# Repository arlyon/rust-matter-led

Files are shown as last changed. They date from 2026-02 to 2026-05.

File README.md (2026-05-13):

# matter-led

A Matter-compatible 5-channel RGBCW LED controller built on a custom PCB
with an ESP32-C6, written entirely in Rust. Pairs natively with Apple Home,
Google Home, and any other Matter controller -- no proprietary hub required.

## Hardware

### Board

The controller is a 2-layer PCB designed in KiCad 9. It accepts 24 V DC
input through a Molex 2601-1106 connector, protected by a 10 A mini blade
fuse (Littelfuse 0297010.WXNV). A Recom R-78E5.0-1.0 switching regulator
steps 24 V down to 5 V / 1 A to power the Waveshare ESP32-C6 module. Two
470 uF electrolytic capacitors (Panasonic EEUFR1V471L) filter the converter
input.

Five AO3400A N-channel MOSFETs in SOT-23 packages switch the LED channels
on the low side. Each gate is driven from a GPIO through a 100 ohm series
resistor; 10 kohm pull-downs hold the gates low during boot. The MOSFETs
switch the 24 V rail directly, so the LED strips see full supply voltage.

### LED strip

The board drives 24 V RGBCCT LED strips with a common-anode, 6-pin
configuration (V+, R, G, B, CW, WW). The target strip uses 5050-package
RGB LEDs alongside 2835-package tunable-white LEDs, with a colour
temperature range of 2000--6500 K and a CRI of 95. At 168 LEDs/m drawing
34.56 W/m, a 5 m reel pulls around 173 W. The strip is IP20 (no
weatherproofing). Five independent PWM channels allow continuous colour
temperature tuning between 2000 K and 6500 K, as well as full-gamut RGB
colour mixing.

An example strip that matches these specs:
https://www.aliexpress.com/item/1005006132338333.html

### Power supply

Use a 24 V DC supply rated for the strip length you intend to drive. The
board fuse is 10 A, so the practical ceiling is around 240 W at the input
connector. A Mean Well LRS-350-24 or equivalent is a reasonable choice for
a full 5 m strip.

### GPIO mapping

| GPIO | Channel |
|---|---|
| 1 | Red |
| 0 | Green |
| 10 | Blue |
| 3 | Cold White |
| 2 | Warm White |
| 9 | BOOT (factory reset) |

## Firmware

The firmware is a `no_std` Rust binary targeting `riscv32imac-unknown-none-elf`.
It requires nightly Rust (minimum 1.88) for `type_alias_impl_trait` and
the alloc error handler.

### Architecture

The async runtime is [Embassy](https://embassy.dev). Hardware access goes
through `esp-hal`, and the Matter protocol stack is
[rs-matter](https://github.com/project-chip/rs-matter) with the
`rs-matter-embassy` integration layer. Networking uses `smoltcp` via
`embassy-net` with DHCPv4 and IPv6 support. BLE commissioning is handled
by `trouble-host` over the ESP32-C6's radio.

The device advertises as a Matter Extended Color Light (device type 0x10D)
on endpoint 1, exposing the following clusters:

- **OnOff** -- power state with smooth 400 ms transitions.
- **LevelControl** -- brightness from 1 to 254 (Matter range).
- **ColorControl** -- hue/saturation mode and colour temperature in mireds
  (153--500, i.e. 6500 K down to 2000 K).
- **Identify** -- cycles through red, green, blue to visually locate the
  device.

A second endpoint (endpoint 2) exposes an On/Off Light Switch that acts as
a "max brightness" override, driving all five channels at the current
brightness level simultaneously.

### PWM control

The LEDC peripheral is configured with a single 13-bit timer at 4882 Hz,
giving 8192 discrete duty levels per channel. A dedicated async task runs
at 50 Hz (20 ms per frame), interpolating between the current and target
PWM state with a cubic ease-in-out curve. RGB transitions are mixed in
Oklab colour space for perceptually uniform blending; CW/WW transitions
use linear interpolation in Kelvin space (converted from mireds). All
output values pass through gamma 2.2 correction before hitting the LEDC
registers.

### Colour temperature

The firmware maps the Matter mired range (153--500) to a mix ratio between
the CW and WW channels. Conversion goes through Kelvin
(`K = 1,000,000 / mireds`) and interpolates linearly in that space, which
is more perceptually uniform than interpolating in mireds directly.

### Memory layout

The ESP32-C6 has 8 MB of flash. The firmware reclaims bootloader RAM for
heap use:

| Region | Size | Purpose |
|---|---|---|
| Heap | 112 KB | General allocations (peak ~72 KB) |
| Bump allocator | 24 KB | rs-matter internals (peak ~16 KB) |
| Flash KV store | 128 KB | Matter fabric and ACL persistence |

The KV store sits at offset `0x700000` and uses `sequential-storage` with
32 x 4 KB sectors.

### Matter commissioning

The discriminator is derived from the last 12 bits of the device MAC
address, giving each board a unique but deterministic identity. The default
passcode is `20202021` (the Matter test value). Pairing data is printed to
the defmt log on boot.

To commission, use any Matter controller and enter the discriminator and
passcode, or generate a QR code with vendor ID `0xFFF1` and product ID
`0x8000`.

### Factory reset

Hold the BOOT button (GPIO 9) during power-on. The firmware erases the
128 KB flash KV store and reboots after a 2-second delay. All Matter
fabrics, ACLs, and saved state are wiped.

## Building

### Prerequisites

Install the toolchain via [mise](https://mise.jdx.dev):

```
mise install
```

This sets up nightly Rust with the `riscv32imac-unknown-none-elf` target
and the `espflash` tool.

Alternatively, install manually:

```
rustup toolchain install nightly
rustup target add riscv32imac-unknown-none-elf
cargo install espflash
```

### Compile and flash

```
cd firmware
cargo build --release
cargo espflash flash --release --monitor
```

The `--monitor` flag opens a serial console after flashing so you can see
defmt log output including the pairing discriminator.

## Hardware CI with KiBot

A GitHub Actions workflow runs [KiBot](https://github.com/INTI-CMNB/KiBot)
on every push or PR that touches schematic, PCB, or KiBot configuration
files. It uses the `ghcr.io/inti-cmnb/kicad9_auto_full` container image
and runs ERC/DRC preflight checks before generating outputs.

### Generated artifacts

All outputs land in `hardware/output/` and are uploaded as build artifacts.

| Directory | Contents |
|---|---|
| `schematics` | Schematic PDF and SVG |
| `gerbers` | Gerber files (F/B Cu, SilkS, Mask, Paste, Edge.Cuts) + Excellon drill |
| `assembly` | Pick-and-place CSV (JLC format, SMD only), full position file, interactive HTML BOM |
| `bom` | JLC BOM (LCSC parts), Mouser/Digikey BOM (non-LCSC parts), Octopart 1-click import |
| `pcb` | Top and bottom layer PDFs |
| `3d` | STEP and VRML 3D models |

The BOM is split by sourcing. Components with an `LCSC` field go into the
JLC BOM for PCBA ordering; everything else (the ESP32-C6 module, Recom
regulator, fuse, connectors) goes into a separate BOM formatted for
Mouser/Digikey with MPN grouping. A third BOM variant is formatted for
[Octopart](https://octopart.com) one-click import -- upload the CSV and
Octopart resolves MPNs across distributors, shows stock and pricing, and
lets you build a cart in one step.

## Bill of materials

### On-board components

| Ref | Part | Value / MPN | Package | LCSC | Notes |
|---|---|---|---|---|---|
| U1 | DC-DC converter | R-78E5.0-1.0 | SIP-3 | -- | 24 V to 5 V, 1 A (Recom) |
| U2 | MCU module | ESP32-C6-Mini | Castellated| -- | Waveshare, RISC-V 160 MHz, WiFi 6 + BLE 5 + Zigbee 3.0, 8 MB flash |
| Q1--Q5 | N-ch MOSFET | AO3400A | SOT-23 | -- | 30 V / 5.7 A, low-side LED switches |
| D1 | Schottky rectifier | SS34 | SMC | C211777 | 3 A / 40 V, reverse polarity protection |
| F1 | Fuse | 10 A | Mini Blade | -- | Littelfuse 0297010.WXNV |
| C1, C2 | Ceramic capacitor | 100 nF | 1206 | C13585  | Decoupling |
| C3 | Electrolytic capacitor | 470 uF 35 V | Radial | -- | EEUFR1V471L, regulator input |
| R1,R3,R5,R7,R9 | Resistor | 100 ohm | 0402 | C25076  | MOSFET gate current limiting |
| R2,R4,R6,R8,R10| Resistor | 10 kohm | 0402 | C25744  | MOSFET gate pull-down |
| J1 | Power input connector  | Molex 2601-1106 | 2-pin | -- | 24 V DC input |
| J2 | LED output connector | XT30U-M | XT30 | -- | RGBCW strip connection |

### Off-board (not on PCB)

| Part | Example | Notes |
|---|---|---|
| 24 V power supply | Mean Well LRS-350-24 | Size to strip length; fuse limits 240 W  |
| RGBCCT LED strip  | 5050 RGB + 2835 CCT, 24 V, IP20 | 2000--6500 K, CRI 95, 168 LEDs/m, 34.56 W/m, 6-pin |

The KiBot CI generates three BOM formats automatically: a JLC-formatted
CSV for LCSC parts (ready for JLCPCB PCBA upload), a Mouser/Digikey BOM
grouped by MPN for manual ordering, and an Octopart CSV for one-click
quoting across distributors. All three are available as build artifacts
under `hardware/output/bom/`.

## Project structure

```
.
├── firmware/           Rust firmware for the ESP32-C6
│   ├── src/bin/        Entry point (main.rs)
│   ├── src/clusters/   Matter cluster handlers (OnOff, LevelControl, ColorControl, Identify)
│   ├── src/led/        PWM control, colour conversion, device state
│   └── tests/          On-target embedded tests
├── hardware/           KiCad 9 schematic and PCB
│   ├── external/       Third-party symbol libraries
│   └── internal/       Custom symbols (Waveshare module)
├── crates/
│   └── sticky-signal/  Async signal primitive (no_std, multi-waiter)
├── config.kibot.yaml   KiBot output definitions
└── .github/workflows/  CI for hardware artifact generation
```

## License

See individual crate and hardware directories for licensing details.

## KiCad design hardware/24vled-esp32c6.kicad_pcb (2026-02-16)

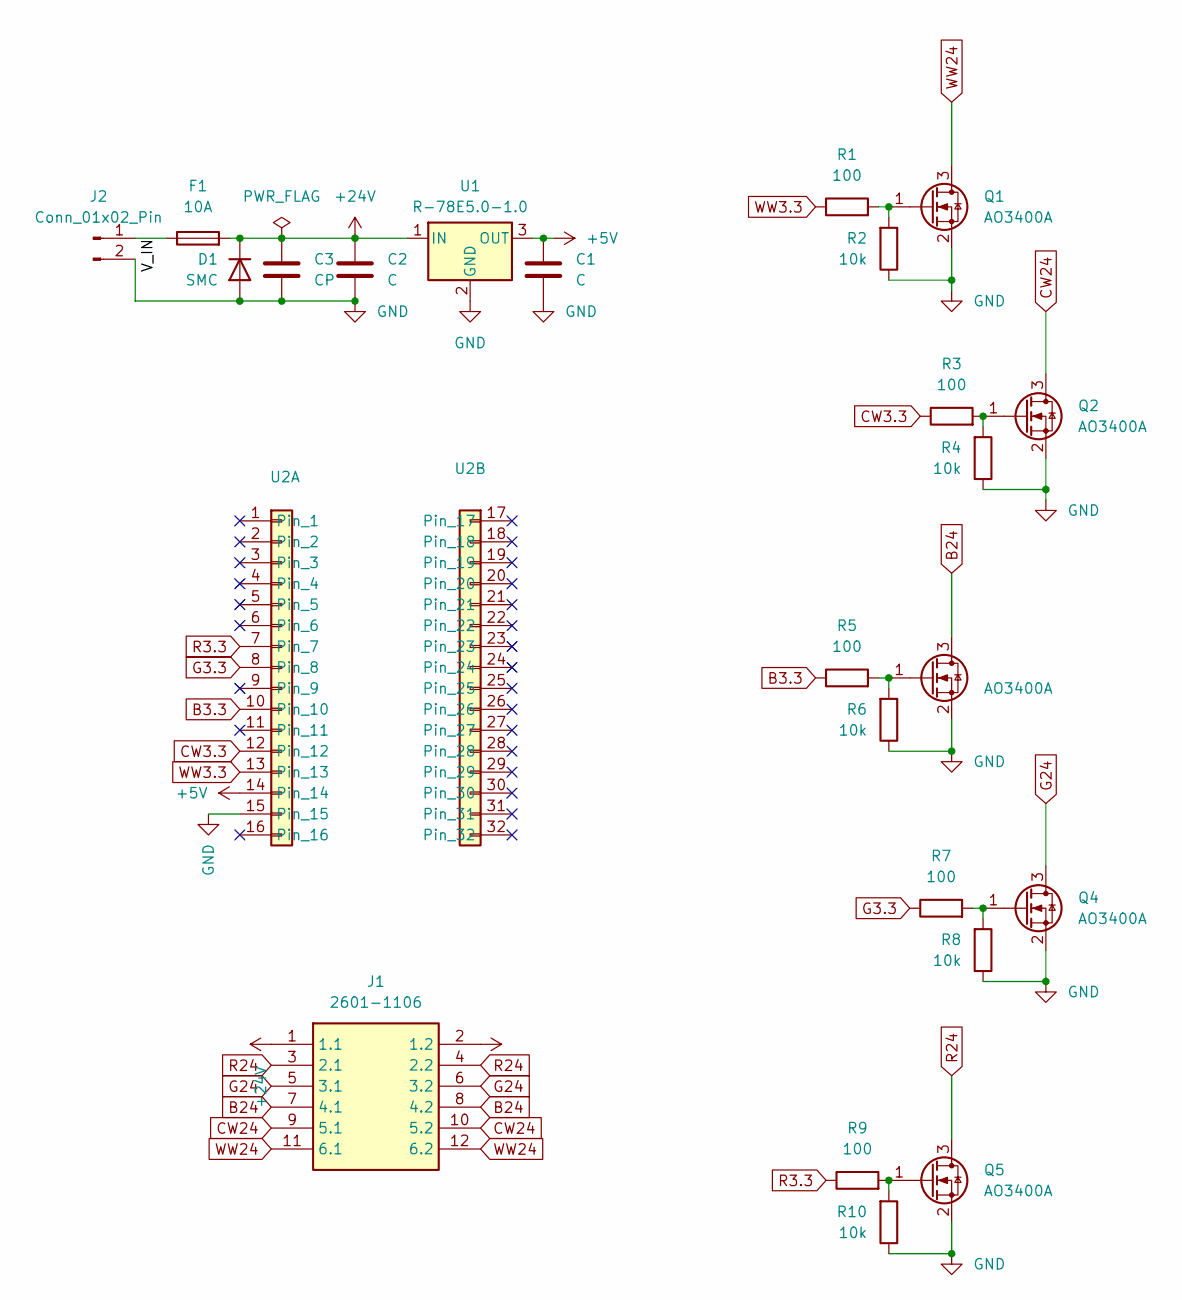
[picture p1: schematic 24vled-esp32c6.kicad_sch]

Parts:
C1, C2: C; C_1206_3216Metric; LCSC C13585
C3: CP; CP_Radial_D8.0mm_P3.50mm
D1: SMC; D_SMC; LCSC C211777
F1: 10A; Fuse_Blade_Mini_directSolder
J1: 2601-1106; 26011106; Manufacturer_Part_Number 2601-1106
J2: Conn_01x02_Pin; AMASS_XT30U-M_1x02_P5.0mm_Vertical
Q1, Q2, Q3, Q4, Q5: AO3400A; SOT-23
R1, R3, R5, R7, R9: 100; R_0402_1005Metric; LCSC C25076
R2, R4, R6, R8, R10: 10k; R_0402_1005Metric; LCSC C25744
U1: R-78E5.0-1.0; Converter_DCDC_RECOM_R-78E-0.5_THT
U2: Waveshare ESP32c6

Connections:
+5V: C1.1, U1.3 (OUT), U2.14
+24V: C2.1, C3.1, D1.1 (K), F1.2, J1.1 (1.1), J1.2 (1.2), U1.1 (IN)
/V_IN: F1.1, J2.1
B3.3: R5.1, U2.10
B24: J1.7 (4.1), J1.8 (4.2), Q3.3 (D)
CW3.3: R3.1, U2.12
CW24: J1.9 (5.1), J1.10 (5.2), Q2.3 (D)
G3.3: R7.1, U2.8
G24: J1.5 (3.1), J1.6 (3.2), Q4.3 (D)
GND: C1.2, C2.2, C3.2, D1.2 (A), J2.2, Q1.2 (S), Q2.2 (S), Q3.2 (S), Q4.2 (S), Q5.2 (S), R2.1, R4.1, R6.1, R8.1, R10.1, U1.2 (GND), U2.15
unnamed: Q1.1 (G), R1.2, R2.2
unnamed: Q2.1 (G), R3.2, R4.2
unnamed: Q3.1 (G), R5.2, R6.2
unnamed: Q4.1 (G), R7.2, R8.2
unnamed: Q5.1 (G), R9.2, R10.2
R3.3: R9.1, U2.7
R24: J1.3 (2.1), J1.4 (2.2), Q5.3 (D)
WW3.3: R1.1, U2.13
WW24: J1.11 (6.1), J1.12 (6.2), Q1.3 (D)

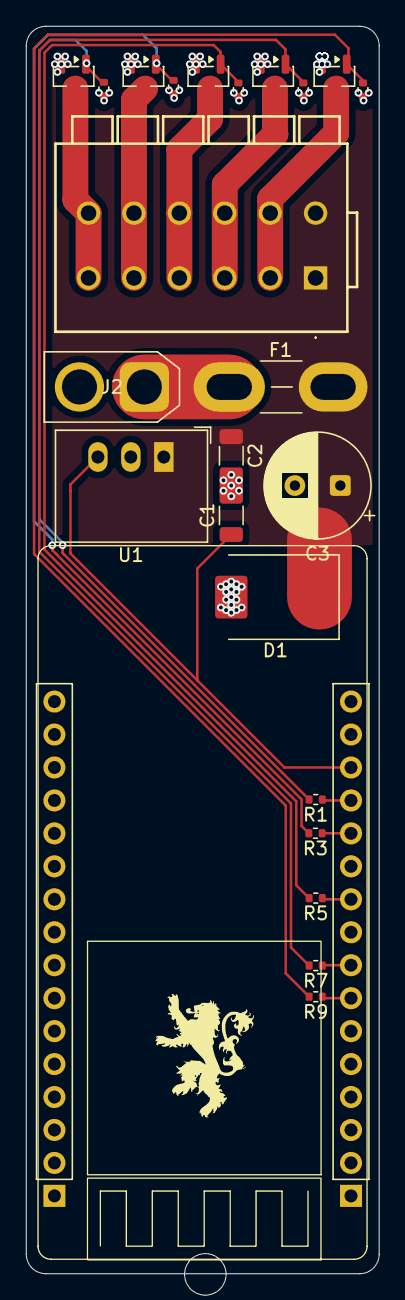
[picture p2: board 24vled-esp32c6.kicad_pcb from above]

Board: 2 copper layers, 27.2 x 96.1 mm, 24 parts (0 on the bottom side), 19 nets.

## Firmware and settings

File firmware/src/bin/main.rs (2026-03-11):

#![no_std]
#![no_main]
#![recursion_limit = "256"]
#![deny(
    clippy::mem_forget,
    reason = "mem::forget is generally not safe to do with esp_hal types"
)]
#![feature(alloc_error_handler)]
#![feature(type_alias_impl_trait)]

extern crate alloc;

use core::pin::pin;
use embedded_storage_async::nor_flash::{ErrorType, NorFlash, ReadNorFlash};
use esp_alloc::heap_allocator;
use esp_storage::{FlashStorage, FlashStorageError};

use rs_matter::utils::init::InitMaybeUninit;
use rs_matter_embassy::matter::dm::devices::test::{TEST_DEV_ATT, TEST_DEV_DET};

use embassy_executor::Spawner;
use esp_hal::{
    clock::CpuClock,
    gpio::{Input, Io, Pull},
    ram,
    rng::Rng,
    timer::timg::TimerGroup,
};

use esp_backtrace as _;
use esp_println as _;

use rs_matter_embassy::wireless::esp::EspWifiDriver;
use rs_matter_embassy::{epoch::epoch, wireless::EmbassyWifiMatterStack};
use rs_matter_embassy::{
    matter::dm::clusters::desc::{self, ClusterHandler as _},
    wireless::EmbassyWifi,
};
use rs_matter_embassy::{
    matter::dm::{Async as MatterAsync, Dataver, EmptyHandler, EpClMatcher},
    persist::EmbassyKvBlobStore,
};

use esp_metadata_generated::memory_range;
use firmware::clusters::color_control::ColorControlHandler;
use firmware::clusters::level_control::AttributeDefaults;
use firmware::clusters::*;
use firmware::device::{LedDeviceLogic, MaxBrightnessSwitch};
use firmware::matter::{LIGHT_ENDPOINT_ID, MAX_BRIGHTNESS_SWITCH_ID, NODE};
use rs_matter::tlv::Nullable;

// we can reclaim RAM from the bootloader!!!
const RECLAIMED_RAM: usize =
    memory_range!("DRAM2_UNINIT").end - memory_range!("DRAM2_UNINIT").start;

const BUMP_SIZE: usize = 24 * 1024; //  typical peak is about 16kb
const HEAP_SIZE: usize = 112 * 1024; // typical peak is about 72kb

// Storage configuration (must match between boot cycles)
// we have 8MB flash, so lets 'reserve' the last 1MB for the storage
const STORAGE_START: u32 = 0x700_000; // Start at a safe offset in flash
const STORAGE_SIZE: u32 = 32 * 4096; // 32 sectors = 128KB

esp_bootloader_esp_idf::esp_app_desc!();

pub struct MatterRng(pub esp_hal::rng::Rng);

static STATIC_CELL: static_cell::StaticCell<EmbassyWifiMatterStack<BUMP_SIZE, ()>> =
    static_cell::StaticCell::new();

impl rand_core::RngCore for MatterRng {
    fn next_u32(&mut self) -> u32 {
        // esp_hal::rng::Rng has a random() method that returns u32
        self.0.random()
    }

    fn next_u64(&mut self) -> u64 {
        let mut buf = [0u8; 8];
        self.fill_bytes(&mut buf);
        u64::from_le_bytes(buf)
    }

    fn fill_bytes(&mut self, dest: &mut [u8]) {
        for chunk in dest.chunks_mut(4) {
            let rand_val = self.0.random().to_le_bytes();
            let len = chunk.len();
            chunk.copy_from_slice(&rand_val[..len]);
        }
    }
}

// rs_matter requires this marker trait to accept the RNG
impl rand_core::CryptoRng for MatterRng {}

/// Factory reset: erase the Matter storage and reboot
async fn factory_reset(mut flash: BlockingFlashStorage<'_>) {
    use embedded_storage::nor_flash::NorFlash as _;

    defmt::warn!("Factory reset initiated!");
    defmt::info!(
        "Erasing flash storage from 0x{:x} to 0x{:x}",
        STORAGE_START,
        STORAGE_START + STORAGE_SIZE
    );

    // Erase the storage area in sector-sized chunks
    if let Err(e) = flash.0.erase(STORAGE_START, STORAGE_START + STORAGE_SIZE) {
        defmt::error!("Failed to erase flash: {:?}", e);
    } else {
        defmt::info!("Flash erased successfully!");
    }

    defmt::info!("Rebooting in 2 seconds...");
    embassy_time::Timer::after(embassy_time::Duration::from_secs(2)).await;

    esp_hal::system::software_reset();
}

#[alloc_error_handler]
fn alloc_error(layout: core::alloc::Layout) -> ! {
    defmt::panic!(
        "OOM: alloc of {} bytes, align {}",
        layout.size(),
        layout.align()
    );
}

#[esp_rtos::main]
async fn main(spawner: Spawner) -> ! {
    defmt::info!("Starting Matter + Direct PWM example (ESP32-C6)...");

    let config = esp_hal::Config::default().with_cpu_clock(CpuClock::max());
    let peripherals = esp_hal::init(config);
    let _io = Io::new(peripherals.IO_MUX);

    // Initialize Heap
    heap_allocator!(size: HEAP_SIZE - RECLAIMED_RAM);
    heap_allocator!(#[ram(reclaimed)] size: RECLAIMED_RAM);

    // Check if BOOT button (GPIO9) is held down for factory reset
    let boot_button = Input::new(
        peripherals.GPIO9,
        esp_hal::gpio::InputConfig::default().with_pull(Pull::Up),
    );
    let factory_reset_requested = boot_button.is_low();

    if factory_reset_requested {
        defmt::warn!("BOOT button held - Factory reset will be performed after initialization");
    }

    // Initialize Embassy Timer Driver
    use esp_hal::interrupt::software::SoftwareInterruptControl;
    let timg0 = TimerGroup::new(peripherals.TIMG0);
    let software_interrupt = SoftwareInterruptControl::new(peripherals.SW_INTERRUPT);
    esp_rtos::start(timg0.timer0, software_interrupt.software_interrupt0);

    defmt::info!("Embassy initialized!");

    // Initialize LEDC for 5-channel LED control
    let ledc_channels = firmware::led::pwm::init_ledc(
        peripherals.LEDC,
        peripherals.GPIO1,  // Red
        peripherals.GPIO0,  // Green
        peripherals.GPIO10, // Blue
        peripherals.GPIO3,  // Cold White
        peripherals.GPIO2,  // Warm White
    );

    // Spawn PWM task
    spawner.spawn(firmware::led::pwm::pwm_task(ledc_channels).unwrap());
    defmt::info!("PWM task spawned");

    // Get MAC address for unique identity
    let mac = esp_hal::efuse::Efuse::mac_address();
    defmt::info!(
        "Device MAC: {:02X}:{:02X}:{:02X}:{:02X}:{:02X}:{:02X}",
        mac[0],
        mac[1],
        mac[2],
        mac[3],
        mac[4],
        mac[5]
    );

    // Generate unique commissioning data based on MAC
    let comm_data = firmware::matter::generate_commissioning_data(mac);
    firmware::matter::log_pairing_info(comm_data.discriminator, firmware::matter::DEFAULT_PASSCODE);

    let stack = STATIC_CELL
        .uninit()
        .init_with(EmbassyWifiMatterStack::<BUMP_SIZE, ()>::init(
            &TEST_DEV_DET,
            comm_data,
            &TEST_DEV_ATT,
            epoch,
        ));

    // Initialize the hardware RNG and wrap it to satisfy rs_matter's rand_core 0.9.x trait bounds
    let hw_rng = Rng::new();
    let matter_rng = MatterRng(hw_rng);

    let crypto =
        rs_matter::crypto::default_crypto::<embassy_sync::blocking_mutex::raw::NoopRawMutex, _>(
            rs_matter_stack::rand::reseeding_csprng(matter_rng, 1000).unwrap(),
            rs_matter::dm::devices::test::DAC_PRIVKEY,
        );

    use rs_matter::crypto::Crypto;

    let mut weak_rand = crypto.weak_rand().unwrap();

    // == Matter Device Definition (Using custom OnOff logic) ==

    // Configure smooth transitions: 400ms (4 deciseconds) for on/off
    // These can be changed via Matter/Home Assistant
    let level_control_defaults = AttributeDefaults {
        on_level: Nullable::none(),
        options: level_control::OptionsBitmap::from_bits(0).unwrap(),
        on_off_transition_time: 4,              // 400ms default for on/off
        on_transition_time: Nullable::some(4),  // 400ms when turning on
        off_transition_time: Nullable::some(4), // 400ms when turning off
        default_move_rate: Nullable::none(),
    };

    // Create handlers (use new() instead of new_standalone() for proper coupling)
    let on_off_handler = OnOffHandler::new_standalone(
        Dataver::new_rand(&mut weak_rand),
        LIGHT_ENDPOINT_ID,
        LedDeviceLogic, // Use our custom logic struct
    );

    let identify_handler = firmware::clusters::identify::IdentifyHandler::new(
        Dataver::new_rand(&mut weak_rand),
        LedDeviceLogic,
    );

    let color_control_handler =
        ColorControlHandler::new(Dataver::new_rand(&mut weak_rand), LedDeviceLogic);

    let level_control_handler = LevelControlHandler::new_standalone(
        Dataver::new_rand(&mut weak_rand),
        LIGHT_ENDPOINT_ID,
        LedDeviceLogic,
        level_control_defaults, // Use custom transition times
    );

    // Max brightness switch handler (Endpoint 2) - standalone since not coupled
    let max_brightness_handler = OnOffHandler::new_standalone(
        Dataver::new_rand(&mut weak_rand),
        MAX_BRIGHTNESS_SWITCH_ID,
        MaxBrightnessSwitch,
    );

    // TODO: figure this out, and use new instead of new_standalone
    // on_off_handler.init(Some(&level_control_handler));
    // level_control_handler.init(Some(&on_off_handler));

    // Chain clusters for the endpoint
    let handler = EmptyHandler
        .chain(
            EpClMatcher::new(
                // Match OnOff cluster on our endpoint
                Some(LIGHT_ENDPOINT_ID),
                Some(firmware::clusters::ON_OFF_FULL_CLUSTER.id), // Use the cluster ID
            ),
            on_off_handler.adapt(),
        )
        .chain(
            EpClMatcher::new(
                Some(LIGHT_ENDPOINT_ID),
                Some(firmware::clusters::identify::CLUSTER_ID),
            ),
            identify_handler.adapt(),
        )
        .chain(
            EpClMatcher::new(
                Some(LIGHT_ENDPOINT_ID),
                Some(firmware::clusters::color_control::CLUSTER_ID),
            ),
            color_control_handler.adapt(),
        )
        .chain(
            EpClMatcher::new(
                Some(LIGHT_ENDPOINT_ID),
                Some(firmware::clusters::LEVEL_CONTROL_FULL_CLUSTER.id),
            ),
            level_control_handler.adapt(),
        )
        .chain(
            // Add the mandatory Descriptor cluster for Endpoint 1
            EpClMatcher::new(Some(LIGHT_ENDPOINT_ID), Some(desc::DescHandler::CLUSTER.id)),
            MatterAsync(desc::DescHandler::new(Dataver::new_rand(&mut weak_rand)).adapt()),
        )
        .chain(
            // Add OnOff cluster for Endpoint 2 (Max Brightness Switch)
            EpClMatcher::new(
                Some(MAX_BRIGHTNESS_SWITCH_ID),
                Some(firmware::clusters::ON_OFF_FULL_CLUSTER.id),
            ),
            max_brightness_handler.adapt(),
        )
        .chain(
            // Add the mandatory Descriptor cluster for Endpoint 2
            EpClMatcher::new(
                Some(MAX_BRIGHTNESS_SWITCH_ID),
                Some(desc::DescHandler::CLUSTER.id),
            ),
            MatterAsync(desc::DescHandler::new(Dataver::new_rand(&mut weak_rand)).adapt()),
        );

    let storage = esp_storage::FlashStorage::new(peripherals.FLASH);
    let storage = BlockingFlashStorage(storage);

    // Handle factory reset if BOOT button was held during startup
    if factory_reset_requested {
        factory_reset(storage).await;
        unreachable!();
    }

    // sequential-storage requires:
    // - Start/end aligned to ERASE_SIZE (4096 bytes for ESP32)
    // - At least 2 sectors (8192 bytes minimum)
    // Using 32 sectors (128KB) for Matter key-value storage (fabrics, certs, ACLs, etc.)
    let kv_store = EmbassyKvBlobStore::new(storage, STORAGE_START..(STORAGE_START + STORAGE_SIZE));

    // Persistence (Dummy for now)
    let persist = stack
        .create_persist_with_comm_window(&crypto, kv_store)
        .await
        .unwrap();

    // == Run the Matter Stack ==
    defmt::info!("Running Matter stack...");
    let matter = pin!(stack.run_coex(
        EmbassyWifi::new(
            // C6 uses WIFI and BLE peripherals
            EspWifiDriver::new(peripherals.WIFI, peripherals.BT),
            weak_rand,
            true,
            stack,
        ),
        &persist,
        &crypto,
        (NODE, handler), // Use the handler chain we built
        (),
    ));

    match matter.await {
        Ok(_) => {
            unreachable!();
        }
        Err(e) => {
            defmt::error!("Matter error: {:?}", e);
            panic!();
        }
    }
}

struct BlockingFlashStorage<'a>(FlashStorage<'a>);

impl ErrorType for BlockingFlashStorage<'_> {
    type Error = FlashStorageError;
}

impl NorFlash for BlockingFlashStorage<'_> {
    const WRITE_SIZE: usize = FlashStorage::WORD_SIZE as _;

    const ERASE_SIZE: usize = FlashStorage::SECTOR_SIZE as _;

    async fn erase(&mut self, from: u32, to: u32) -> Result<(), Self::Error> {
        embedded_storage::nor_flash::NorFlash::erase(&mut self.0, from, to)
    }

    async fn write(&mut self, offset: u32, bytes: &[u8]) -> Result<(), Self::Error> {
        embedded_storage::nor_flash::NorFlash::write(&mut self.0, offset, bytes)
    }
}

impl ReadNorFlash for BlockingFlashStorage<'_> {
    const READ_SIZE: usize = FlashStorage::WORD_SIZE as _;

    async fn read(&mut self, offset: u32, bytes: &mut [u8]) -> Result<(), Self::Error> {
        embedded_storage::nor_flash::ReadNorFlash::read(&mut self.0, offset, bytes)
    }

    fn capacity(&self) -> usize {
        embedded_storage::nor_flash::ReadNorFlash::capacity(&self.0)
    }
}

/// The esp storage is synchronous, so we just provide an async wrapper.
///
/// THIS WILL STILL BLOCK
/// see: https://github.com/esp-rs/esp-storage/issues/39#issuecomment-1980991446
impl embedded_storage_async::nor_flash::MultiwriteNorFlash for BlockingFlashStorage<'_> {}

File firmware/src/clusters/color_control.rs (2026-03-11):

use crate::led::{DEVICE_STATE, TARGET_STATE, TargetState};
use core::cell::Cell;
use rs_matter::{
    dm::{Access, Cluster, Dataver, HandlerContext, Quality},
    error::Error,
};

use crate::clusters::decl::color_control::{
    AttributeId, ColorCapabilitiesBitmap, ColorLoopSetRequest, ColorModeEnum, CommandId,
    EnhancedColorModeEnum, EnhancedMoveHueRequest, EnhancedMoveToHueAndSaturationRequest,
    EnhancedMoveToHueRequest, EnhancedStepHueRequest, MoveColorRequest,
    MoveColorTemperatureRequest, MoveHueRequest, MoveSaturationRequest, MoveToColorRequest,
    MoveToColorTemperatureRequest, MoveToHueAndSaturationRequest, MoveToHueRequest,
    MoveToSaturationRequest, OptionsBitmap, StepColorRequest, StepColorTemperatureRequest,
    StepHueRequest, StepSaturationRequest, StopMoveStepRequest,
};

use super::decl::color_control::ClusterAsyncHandler;

pub const CLUSTER_ID: u32 = 0x0300;

pub const CLUSTER: Cluster<'static> = Cluster::new(
    CLUSTER_ID,
    4,                  // revision
    0x01 | 0x02 | 0x10, // hue/sat + enhanced hue + color temp
    &[
        rs_matter::dm::Attribute::new(AttributeId::ColorMode as u32, Access::RV, Quality::NONE),
        rs_matter::dm::Attribute::new(
            AttributeId::EnhancedColorMode as u32,
            Access::RV,
            Quality::NONE,
        ),
        rs_matter::dm::Attribute::new(
            AttributeId::ColorCapabilities as u32,
            Access::RV,
            Quality::NONE,
        ),
        rs_matter::dm::Attribute::new(AttributeId::RemainingTime as u32, Access::RV, Quality::NONE),
        rs_matter::dm::Attribute::new(AttributeId::Options as u32, Access::RWVM, Quality::NONE),
        // --- Hue & Saturation (0x01) ---
        rs_matter::dm::Attribute::new(AttributeId::CurrentHue as u32, Access::RV, Quality::NONE),
        rs_matter::dm::Attribute::new(
            AttributeId::CurrentSaturation as u32,
            Access::RV,
            Quality::NONE,
        ),
        // --- Enhanced Hue (0x02) ---
        rs_matter::dm::Attribute::new(
            AttributeId::EnhancedCurrentHue as u32,
            Access::RV,
            Quality::NONE,
        ),
        // --- Color Temperature (0x10) ---
        rs_matter::dm::Attribute::new(
            AttributeId::ColorTemperatureMireds as u32,
            Access::RV,
            Quality::NONE,
        ),
        rs_matter::dm::Attribute::new(
            AttributeId::ColorTempPhysicalMinMireds as u32,
            Access::RV,
            Quality::NONE,
        ),
        rs_matter::dm::Attribute::new(
            AttributeId::ColorTempPhysicalMaxMireds as u32,
            Access::RV,
            Quality::NONE,
        ),
        // Startup color temp should be Non-Volatile (survives reboots) and Nullable (if not set)
        rs_matter::dm::Attribute::new(
            AttributeId::StartUpColorTemperatureMireds as u32,
            Access::RWVM,
            Quality::from_bits_truncate(Quality::N.bits() | Quality::X.bits()),
        ),
        // --- XY Color Space (not supported, but stub to prevent errors) ---
        rs_matter::dm::Attribute::new(AttributeId::CurrentX as u32, Access::RV, Quality::NONE),
        rs_matter::dm::Attribute::new(AttributeId::CurrentY as u32, Access::RV, Quality::NONE),
    ],
    &[
        rs_matter::dm::Command::new(CommandId::StopMoveStep as u32, None, Access::NEED_OPERATE), // StopMoveStep
        // --- Hue & Saturation Commands ---
        rs_matter::dm::Command::new(CommandId::MoveToHue as u32, None, Access::NEED_OPERATE),
        rs_matter::dm::Command::new(
            CommandId::MoveToSaturation as u32,
            None,
            Access::NEED_OPERATE,
        ),
        rs_matter::dm::Command::new(
            CommandId::MoveToHueAndSaturation as u32,
            None,
            Access::NEED_OPERATE,
        ),
        rs_matter::dm::Command::new(CommandId::StepHue as u32, None, Access::NEED_OPERATE), // StepHue
        rs_matter::dm::Command::new(CommandId::MoveSaturation as u32, None, Access::NEED_OPERATE), // MoveSaturation
        rs_matter::dm::Command::new(CommandId::StepSaturation as u32, None, Access::NEED_OPERATE), // StepSaturation
        // --- Enhanced Hue Commands ---
        rs_matter::dm::Command::new(
            CommandId::EnhancedMoveToHue as u32,
            None,
            Access::NEED_OPERATE,
        ), // EnhancedMoveToHue
        rs_matter::dm::Command::new(
            CommandId::EnhancedMoveHue as u32,
            None,
            Access::NEED_OPERATE,
        ), // EnhancedMoveHue
        rs_matter::dm::Command::new(
            CommandId::EnhancedStepHue as u32,
            None,
            Access::NEED_OPERATE,
        ), // EnhancedStepHue
        rs_matter::dm::Command::new(
            CommandId::EnhancedMoveToHueAndSaturation as u32,
            None,
            Access::NEED_OPERATE,
        ), // EnhancedMoveToHueAndSaturation
        // --- Color Temp Commands ---
        rs_matter::dm::Command::new(
            CommandId::MoveToColorTemperature as u32,
            None,
            Access::NEED_OPERATE,
        ),
        rs_matter::dm::Command::new(
            CommandId::MoveColorTemperature as u32,
            None,
            Access::NEED_OPERATE,
        ), // MoveColorTemperature
        rs_matter::dm::Command::new(
            CommandId::StepColorTemperature as u32,
            None,
            Access::NEED_OPERATE,
        ), // StepColorTemperature
    ],
    rs_matter::with!(all),
    rs_matter::with!(all),
);

pub trait ColorControlHooks {
    fn on_color_control(&self, hue: u8, saturation: u8, temp: u16);
}

pub struct ColorControlHandler<'a, H: ColorControlHooks> {
    dataver: Dataver,
    hooks: H,
    hue: Cell<u8>,
    saturation: Cell<u8>,
    temp: Cell<u16>,
    _phantom: core::marker::PhantomData<&'a ()>,
}

impl<'a, H: ColorControlHooks> ColorControlHandler<'a, H> {
    pub fn new(dataver: Dataver, hooks: H) -> Self {
        Self {
            dataver,
            hooks,
            hue: Cell::new(0),
            saturation: Cell::new(0),
            temp: Cell::new(250), // Default 4000K
            _phantom: core::marker::PhantomData,
        }
    }

    pub const fn adapt(self) -> super::decl::color_control::HandlerAsyncAdaptor<Self> {
        super::decl::color_control::HandlerAsyncAdaptor(self)
    }

    fn notify(&self) {
        self.hooks
            .on_color_control(self.hue.get(), self.saturation.get(), self.temp.get());
    }
}
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

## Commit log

2025-10-24 Added raw files for cleaning and project setup
    [24vled-esp32c6.kicad_pcb, 24vled-esp32c6.kicad_sch, 2604-1106.stp]
2025-10-24 move to hw folder
    [24vled-esp32c6.kicad_pcb, 24vled-esp32c6.kicad_sch, 2604-1106.stp]
2025-10-24 add esp32c6 template
2025-10-26 hardware v1
    [24vled-esp32c6.kicad_pcb, 24vled-esp32c6.kicad_sch]
2025-10-27 hardware v2
    [24vled-esp32c6.kicad_pcb, 24vled-esp32c6.kicad_sch, 2604-1106.stp]
2025-11-05 fix schematic warnings and kibot
    [24vled-esp32c6.kicad_sch]
2025-11-05 fix all pcb warnings and use larger resistors
    [24vled-esp32c6.kicad_pcb, 24vled-esp32c6.kicad_sch]
2025-11-05 update pages
    [24vled-esp32c6.kicad_pcb]
2025-11-05 jlc formatting for bom and pick-n-place
2026-02-15 add the large cap and remove the flyback diodes
    [24vled-esp32c6.kicad_pcb, 24vled-esp32c6.kicad_sch]
2026-02-15 final version!
    [24vled-esp32c6.kicad_pcb, 24vled-esp32c6.kicad_sch]
2026-02-15 fix warnings and add part numbers
    [24vled-esp32c6.kicad_pcb, 24vled-esp32c6.kicad_sch]
2026-02-15 update part number
    [24vled-esp32c6.kicad_pcb, 24vled-esp32c6.kicad_sch]
2026-02-15 add some more part numbers
    [24vled-esp32c6.kicad_pcb, 24vled-esp32c6.kicad_sch]
2026-02-15 change to 3.5mm file
    [24vled-esp32c6.kicad_pcb, 24vled-esp32c6.kicad_sch]
2026-02-15 add m.2 style cutout
    [24vled-esp32c6.kicad_pcb]
2026-02-15 ignore edge cut violation
2026-02-15 replace with npth for financial reasons
    [24vled-esp32c6.kicad_pcb]
2026-02-16 get rid of copper
    [24vled-esp32c6.kicad_pcb]
2026-02-16 add octopart bom generation
2026-02-16 fix filters
2026-02-16 add bom parts
    [24vled-esp32c6.kicad_sch]
2026-02-16 add fuse and fix filtering
    [24vled-esp32c6.kicad_sch]
2026-03-11 integrate basic (broken) PWM
    [device.rs, ledc.rs, main.rs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]
2026-03-11 switch to LEDC
2026-03-11 fix broken timers
2026-03-11 MAX BRIGHTNESS mode and some ergonomics
    - 13 bit duty + 4.8khz
    - on/off fading animations
    - gamma correction
    - oklab color space
    [color_control.rs, device.rs, main.rs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]
